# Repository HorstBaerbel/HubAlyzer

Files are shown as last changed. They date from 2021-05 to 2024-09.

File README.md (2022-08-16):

!!! WORK IN PROGRESS !!!

# HubAlyzer

<p align="center">
    
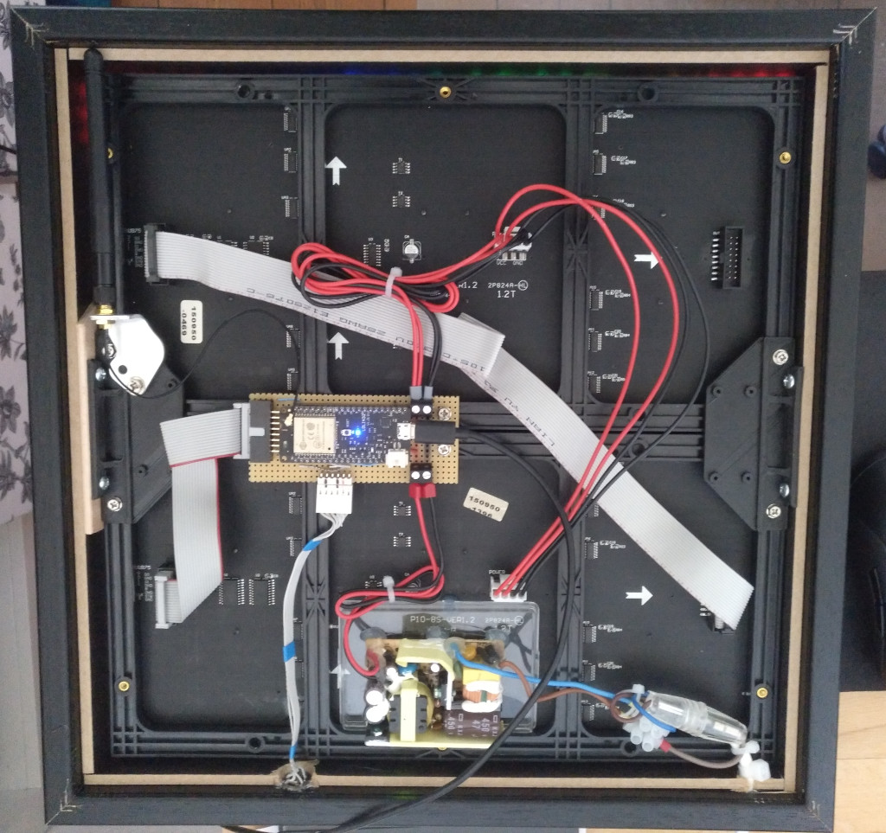
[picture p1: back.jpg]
back
        
    </span>
</p>

## Making the PCB

See the [KiCad](KiCad) directory for the PCB files. You can upload the PCB file straight to e.g. [Aisler.net](Aisler.net) and get some pretty PCBs made.

<p align="center">
    <span>
        <img src="pcb.jpg" width=80%;" title="pcb">
    </span>
</p>

## Updating your network configuration

Edit [HubAlyzer/network_config.h](HubAlyzer/network_config.h) and put your WiFi network and password there. Make sure NOT to commit the file and upload to GitHub when forking the repo!

## Problems compiling the Arduino code

Recently there were some problems with SmartMatrix and the ESP32 Arduino libraries, see [this](https://github.com/pixelmatix/SmartMatrix/issues/165).

## Problems flashing the Arduino code

If the Arduino IDE fails to connect to the board / upload the code, see [this](https://github.com/espressif/arduino-esp32/issues/2516).

## License

If you want to build your own soft- or hardware based on this, you can. See the [MIT LICENSE](LICENSE).

## TODO

* Clean up code
* Clean up esp32-i2s-slm fork
* Merge ArduinoFFT master
* More draw functions
* Draw function switching
* Add rotary encoder handling
* And Bluetooth MIDI and/or WiFi interface

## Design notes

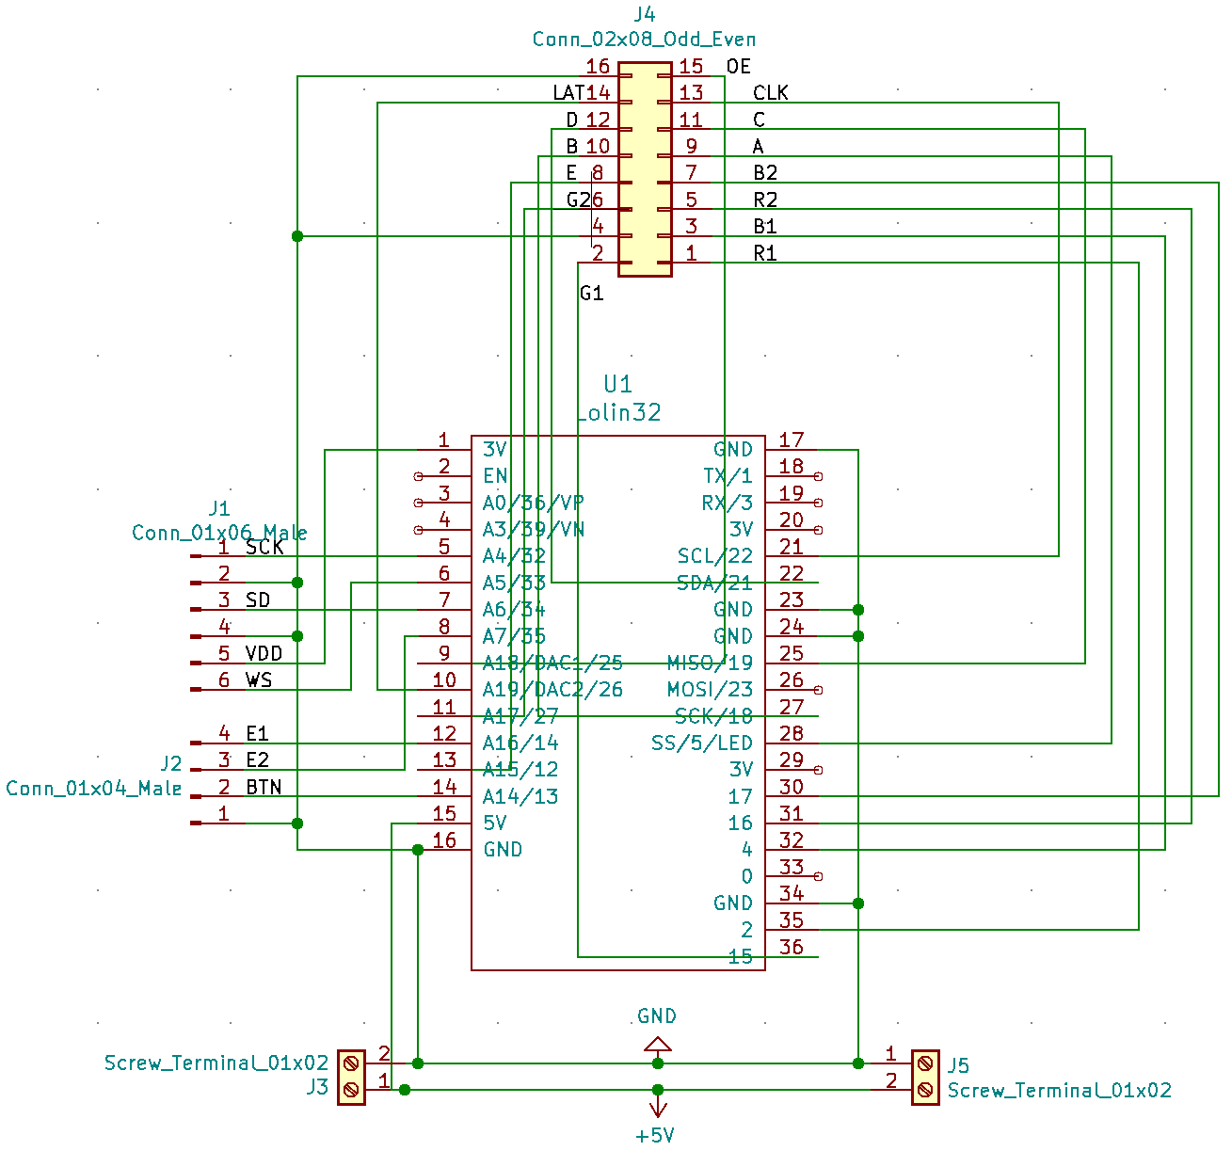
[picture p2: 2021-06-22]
schematics.png

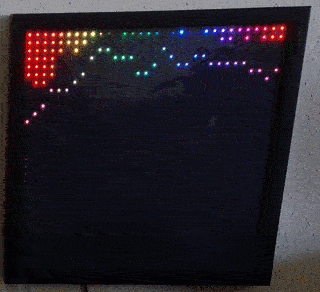
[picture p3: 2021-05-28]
animation.gif

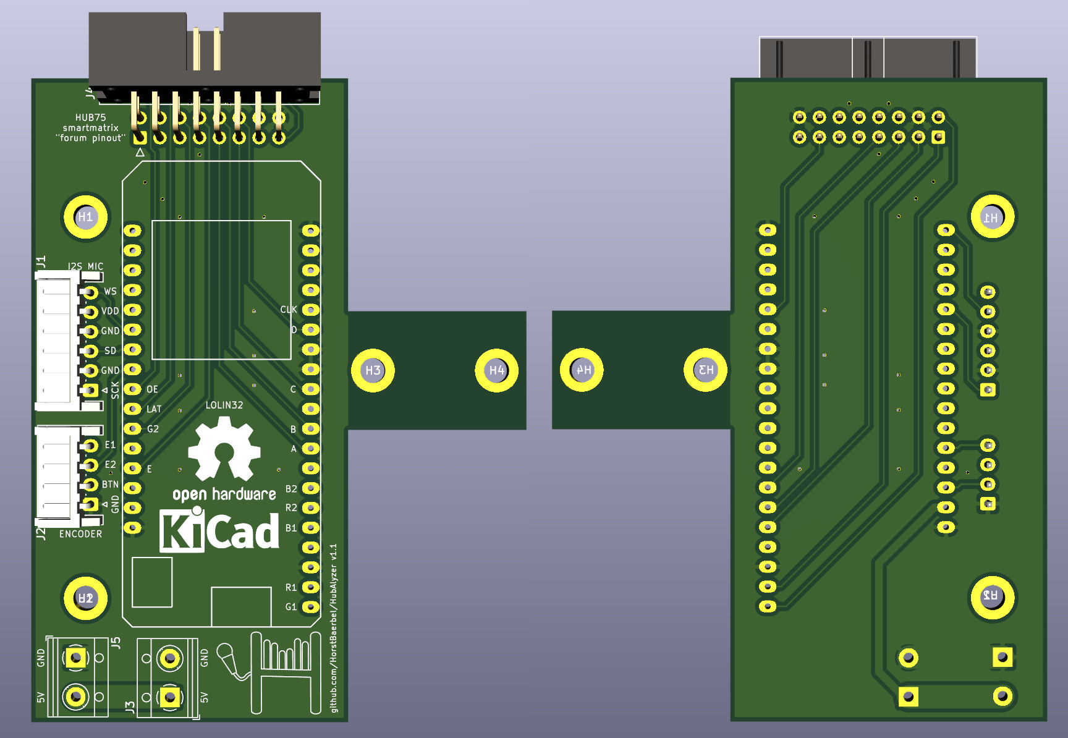
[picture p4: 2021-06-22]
pcb.jpg

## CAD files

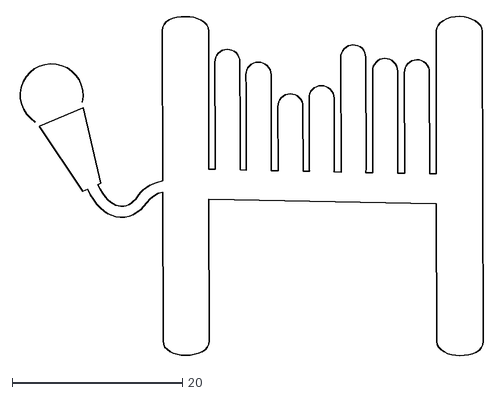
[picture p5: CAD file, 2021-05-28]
KiCad/logo.dxf
54.9 x 39.9

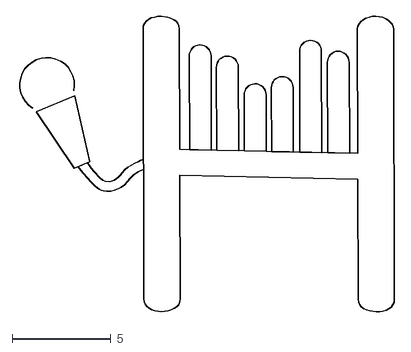
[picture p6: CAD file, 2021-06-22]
logo.dxf
19.2 x 15.0

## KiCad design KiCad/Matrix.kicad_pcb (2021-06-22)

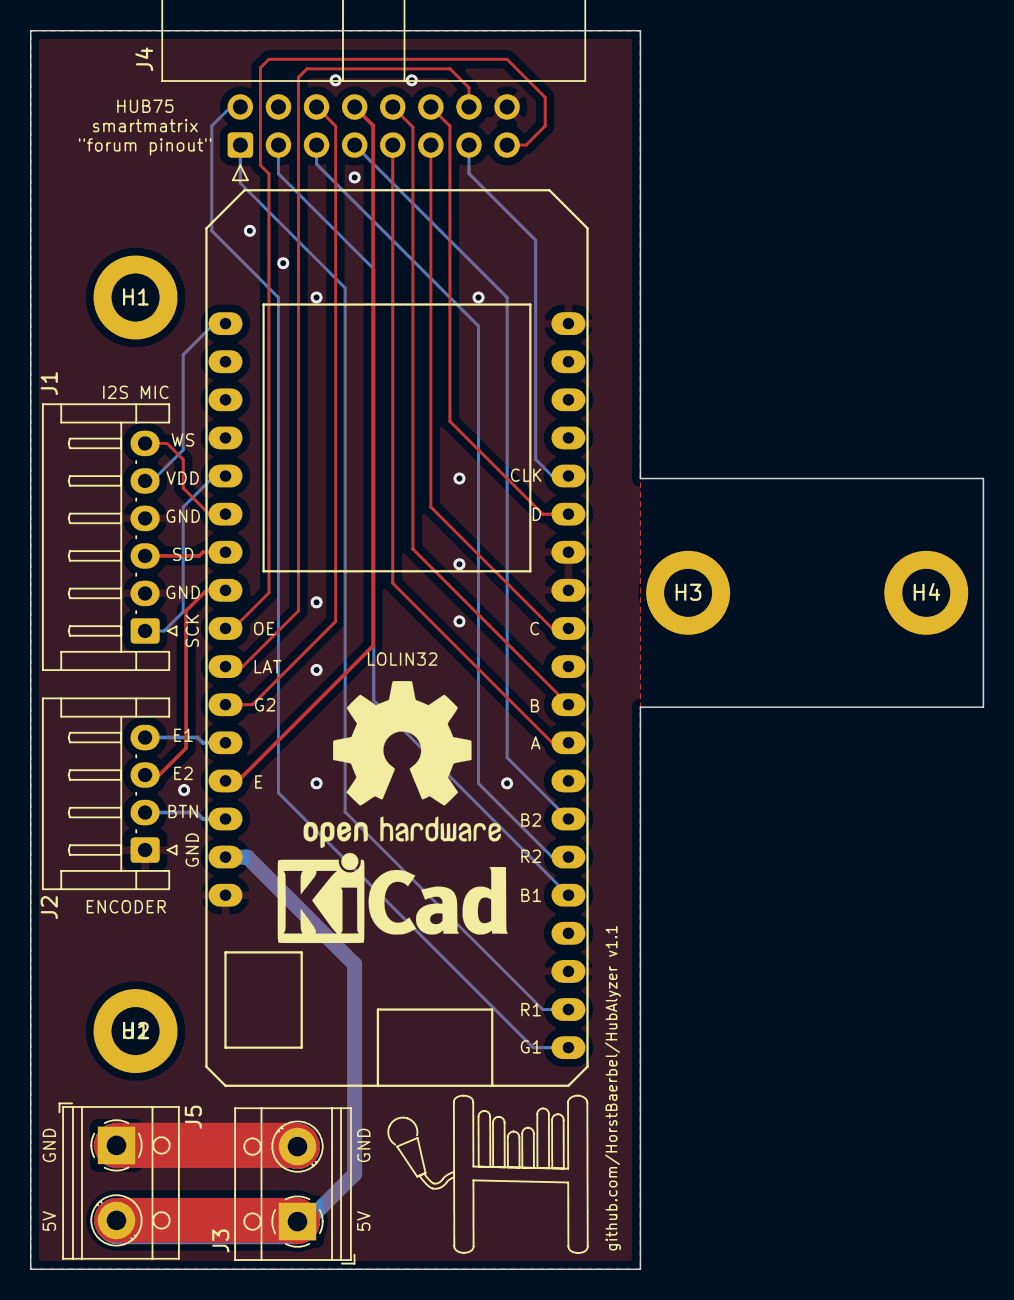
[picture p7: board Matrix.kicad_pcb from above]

Board: 2 copper layers, 63.5 x 82.5 mm, 12 parts (0 on the bottom side), 23 nets.

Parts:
H1, H2, H3, H4: MountingHole; MountingHole_3.2mm_M3_DIN965_Pad
H5: OH logo; OSHW-Logo2_14.6x12mm_SilkScreen
H6: KiCad logo; KiCad-Logo_6mm_SilkScreen
J1: Conn_01x06_Male; JST_EH_S6B-EH_1x06_P2.50mm_Horizontal
J2: Conn_01x04_Male; JST_EH_S4B-EH_1x04_P2.50mm_Horizontal
J3, J5: Screw_Terminal_01x02; TerminalBlock_RND_205-00012_1x02_P5.00mm_Horizontal
J4: Conn_02x08_Odd_Even; IDC-Header_2x08_P2.54mm_Horizontal
U1: Lolin32

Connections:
+5V: J3.1, J5.2, U1.15
/A: J4.9, U1.28
/B: J4.10, U1.27
/B1: J4.3, U1.32
/B2: J4.7, U1.30
/BTN: J2.2, U1.14
/C: J4.11, U1.25
/CLK: J4.13, U1.21
/D: J4.12, U1.22
/E: J4.8, U1.13
/E1: J2.4, U1.12
/E2: J2.3, U1.8
/G1: J4.2, U1.36
/G2: J4.6, U1.11
/LAT: J4.14, U1.10
/OE: J4.15, U1.9
/R1: J4.1, U1.35
/R2: J4.5, U1.31
/SCK: J1.1, U1.5
/SD: J1.3, U1.7
/VDD: J1.5, U1.1
/WS: J1.6, U1.6
GND: J1.2, J1.4, J2.1, J3.2, J4.4, J4.16, J5.1, U1.16, U1.17, U1.23, U1.24, U1.34

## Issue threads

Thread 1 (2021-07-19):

'ArduinoFFT' was not declared in this scope

wilson3682, 2021-07-19:
Hi, when I try to compile the sketch, this is the error I'm getting. Do you know what could be happening? All libraries needed have been installed including the arduinoFFT library.

line 122   auto fft = ArduinoFFT<float>(real, imag, SAMPLE_COUNT, SAMPLE_RATE_HZ, weighingFactors);

Thanks for your help!

HorstBaerbel, 2021-07-19:
Hi wilson3682. You need to use the [development version](https://github.com/kosme/arduinoFFT/tree/develop) of the ArduinoFFT library.

HorstBaerbel, 2021-07-19:
There's also some files still missing due to problems with the submodules. I will update the code in the next few days when I find time and respond here.

wilson3682, 2021-07-19:
Thanks HorsBaerbel for your help! I deleted the arduinoFFT library installed through arduino and placed the dev library manually and now it compiles. Thanks again!

HorstBaerbel, 2021-07-19:
I'd be surprised if it worked because you're probably missing some submodule code. I've updated the repos with the submodules and my current version of the code, but this is WIP. Will update the code in the next weeks. I've killed my ESP32 and am currently waiting for an replacement...

Closed 2021-07-19.

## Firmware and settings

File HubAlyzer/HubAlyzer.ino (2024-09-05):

/*
   Based on SpectrumAnalyzerBasic by Paul Stoffregen included in the Teensy Audio Library
   Modified by Jason Coon for the SmartMatrix Library
   If you are having trouble compiling, see
   the troubleshooting instructions here:
   https://github.com/pixelmatix/SmartMatrix/#external-libraries

   Also based on the ESP32 I2S SLM project by Ivan Kostoski:
   https://github.com/ikostoski/esp32-i2s-slm

   Requires the following libraries:
   Arduino Fast Fourier Transform library: https://github.com/kosme/arduinoFFT
   SmartMatrix v4 or higher: https://github.com/pixelmatix/SmartMatrix/releases
*/

#include "esp32-i2s-slm/filters.h"
#include "esp32-i2s-slm/i2s_mic.h"
#include "approx.h"  // fast log10f and sincosf approximation
#include <cmath>

static constexpr unsigned SAMPLE_RATE_HZ = 48000;  // Hz, fixed to design of IIR filters. Determines maximum frequency that can be analysed by the FFT Fmax=sampleF/2.
static constexpr unsigned SAMPLE_COUNT = 1024;      // ~10ms sample time, must be power-of-two
float samples[SAMPLE_COUNT];                       // Raw microphone sample storage

// NOTE: Some microphones require at least a DC-Blocker filter
#define MIC_EQUALIZER INMP441                    // See below for defined IIR filters or set to 'None' to disable
static constexpr float MIC_OFFSET_DB = 3.0103f;  // Default offset (sine-wave RMS vs. dBFS). Modify this value for linear calibration
// Customize these values from microphone datasheet
static constexpr int MIC_SENSITIVITY = -26.0f;  // dBFS value expected at MIC_REF_DB (Sensitivity value from datasheet)
static constexpr int MIC_REF_DB = 94.0f;        // Value at which point sensitivity is specified in datasheet (dB)
static constexpr int MIC_OVERLOAD_DB = 120.0f;  // dB - Acoustic overload point / Maximum Acoustic Input
static constexpr int MIC_NOISE_DB = 33.0f;      // dB - Noise floor
static constexpr unsigned MIC_BITS = 24;        // valid number of bits in I2S data

constexpr float MIC_REF_AMPL = powf(10.0f, float(MIC_SENSITIVITY) / 20.0f) * ((1 << (MIC_BITS - 1)) - 1);  // Microphone reference amplitude value

// Convert microphone amplitude to dB values
float MicAmplitudeToDb(float v) {
  return MIC_OFFSET_DB + MIC_REF_DB + 20.0f * log10f_fast(v / MIC_REF_AMPL);
}

auto mic = Microphone_I2S<SAMPLE_COUNT, 33, 32, 34, I2S_NUM_0, MIC_BITS, false, SAMPLE_RATE_HZ>(MIC_EQUALIZER);

// ------------------------------------------------------------------------------------------

#include "fft.h"
#include "normalization.h"
#include "spectrum.h"
#include "beat_detection.h"

static constexpr unsigned NR_OF_BANDS = 32;
static constexpr unsigned MAX_ANALYSIS_FREQUENCY_HZ = 4000;

auto fft = FFT<SAMPLE_COUNT, SAMPLE_RATE_HZ>(&samples);
auto normalization = Normalization<SAMPLE_COUNT, MIC_NOISE_DB, MIC_OVERLOAD_DB, MAX_ANALYSIS_FREQUENCY_HZ, SAMPLE_RATE_HZ>(MicAmplitudeToDb);
auto spectrum = Spectrum<SAMPLE_COUNT, NR_OF_BANDS, MAX_ANALYSIS_FREQUENCY_HZ, SAMPLE_RATE_HZ>();
auto beats = BeatDetection<SAMPLE_COUNT, MAX_ANALYSIS_FREQUENCY_HZ, SAMPLE_RATE_HZ, 50>();

// ------------------------------------------------------------------------------------------

#include <WiFi.h>

//#define ENABLE_OTA
#ifdef ENABLE_OTA
#include <ESPmDNS.h>
#include <WiFiUdp.h>
#include <ArduinoOTA.h>
#endif

//#define ENABLE_BLUETOOTH
#ifdef ENABLE_BLUETOOTH
#include "BluetoothSerial.h"
//#include "esp_gap_bt_api.h"
#if !defined(CONFIG_BT_ENABLED) || !defined(CONFIG_BLUEDROID_ENABLED)
#error Bluetooth is not enabled! Please run `make menuconfig` to and enable it
#endif
BluetoothSerial SerialBT;
#endif

// Configure your WiFi and Bluetooth settings here:
#include "network_config.h"

// ------------------------------------------------------------------------------------------

#ifndef GPIO_PIN_MUX_REG
#include "esp32-hal.h"
#include "hal/gpio_types.h"
#include "soc/gpio_periph.h"
#endif

#define GPIOPINOUT ESP32_FORUM_PINOUT
#include <MatrixHardware_ESP32_V0.h>
#include <SmartMatrix.h>

#define COLOR_DEPTH 24                                                    // known working: 24, 48 - If the sketch uses type `rgb24` directly, COLOR_DEPTH must be 24
static constexpr unsigned kMatrixWidth = 32;                              // known working: 32, 64, 96, 128
static constexpr unsigned kMatrixHeight = 32;                             // known working: 16, 32, 48, 64
static constexpr unsigned kRefreshDepth = 24;                             // known working: 24, 36, 48
static constexpr unsigned kDmaBufferRows = 4;                             // known working: 2-4, use 2 to save memory, more to keep from dropping frames and automatically lowering refresh rate
static constexpr unsigned kPanelType = SMARTMATRIX_HUB75_16ROW_MOD8SCAN;  // use SMARTMATRIX_HUB75_16ROW_MOD8SCAN for common 16x32 panels
static constexpr unsigned kMatrixOptions = (SM_HUB75_OPTIONS_NONE);       // see http://docs.pixelmatix.com/SmartMatrix for options
static constexpr unsigned kBackgroundLayerOptions = (SM_BACKGROUND_OPTIONS_NONE);
SMARTMATRIX_ALLOCATE_BUFFERS(matrix, kMatrixWidth, kMatrixHeight, kRefreshDepth, kDmaBufferRows, kPanelType, kMatrixOptions);
SMARTMATRIX_ALLOCATE_BACKGROUND_LAYER(backgroundLayer, kMatrixWidth, kMatrixHeight, COLOR_DEPTH, kBackgroundLayerOptions);

// ------------------------------------------------------------------------------------------

#include "effectpipeline.h"
#include "effects_draw.h"
#include "effects_spectrum.h"
#include "effects_feedback.h"
#include "screen.h"

auto screen = SMLayerScreen<kMatrixWidth, kMatrixHeight, kBackgroundLayerOptions>(backgroundLayer);
auto effects = std::vector<Effect::SPtr>({ std::make_shared<Effects::FillColor<kMatrixWidth, kMatrixHeight, Effect::Type::ToDestination>>(), std::make_shared<Effects::DrawSpectrum<kMatrixWidth, kMatrixHeight, NR_OF_BANDS>>() });
//auto effects = std::vector<Effect::SPtr>({ std::make_shared<Effects::MoveFromCenter<kMatrixWidth, kMatrixHeight>>(), std::make_shared<Effects::ChangeBrightness<kMatrixWidth, kMatrixHeight>>(), std::make_shared<Effects::DrawSpectrum<kMatrixWidth, kMatrixHeight, NR_OF_BANDS>>() });
auto pipeline = EffectPipeline<kMatrixWidth, kMatrixHeight>(effects);

// TODO: Functions to randomize effect pipeline and configure effects

// ------------------------------------------------------------------------------------------

#ifdef ENABLE_BLUETOOTH
void bluetoothCallback(esp_spp_cb_event_t event, esp_spp_cb_param_t *param) {
  Serial.print("Bluetooth event: ");
  Serial.println(event);
  if (event == ESP_SPP_SRV_OPEN_EVT) {
    Serial.println("Client Connected");
  }
  if (event == ESP_SPP_CLOSE_EVT) {
    Serial.println("Client disconnected");
  }
}
#endif

#ifdef ENABLE_OTA
void checkOTA() {
  static auto lastCheckTime = millis();
  auto now = millis();
  if (now - lastCheckTime >= 2000) {
    lastCheckTime = now;
    ArduinoOTA.handle();
  }
}
#endif

void setup() {
  Serial.begin(115200);
  Serial.println("Running setup");
  // Generate host name for WiFi and Bluetooth
  String chipId = String((uint32_t)ESP.getEfuseMac(), HEX);
  chipId.toUpperCase();
  String hostName = String("Matrix-") + chipId;

#ifdef ENABLE_OTA
  // Set up WiFi
  Serial.println("Setting up WiFi");
  WiFi.hostname(hostName);
  WiFi.mode(WIFI_STA);
  WiFi.begin(wifiSsid, wifiPassword);
  while (WiFi.waitForConnectResult() != WL_CONNECTED) {
    Serial.println("WiFi connection Failed! Rebooting...");
    delay(5000);
    ESP.restart();
  }
  // Set up OTA updates
  Serial.println("Setting up OTA updates");
  ArduinoOTA.onStart([]() {
              String type;
              if (ArduinoOTA.getCommand() == U_FLASH)
                type = "sketch";
              else  // U_SPIFFS
                type = "filesystem";
              // NOTE: if updating SPIFFS this would be the place to unmount SPIFFS using SPIFFS.end()
              Serial.println("Start updating " + type);
            })
    .onEnd([]() {
      Serial.println("\nEnd");
    })
    .onProgress([](unsigned int progress, unsigned int total) {
      Serial.printf("Progress: %u%%\r", (progress / (total / 100)));
    })
    .onError([](ota_error_t error) {
      Serial.printf("Error[%u]: ", error);
      if (error == OTA_AUTH_ERROR)
        Serial.println("Auth Failed");
      else if (error == OTA_BEGIN_ERROR)
        Serial.println("Begin Failed");
      else if (error == OTA_CONNECT_ERROR)
        Serial.println("Connect Failed");
      else if (error == OTA_RECEIVE_ERROR)
        Serial.println("Receive Failed");
      else if (error == OTA_END_ERROR)
        Serial.println("End Failed");
    });
  ArduinoOTA.begin();
  Serial.print("Hostname: ");
  Serial.println(hostName);
  Serial.print("IP address: ");
  Serial.println(WiFi.localIP());
#else
  // Turn Wifi off
  Serial.println("Turning WiFi off");
  WiFi.mode(WIFI_OFF);
#endif

#ifdef ENABLE_BLUETOOTH
  // SerialBT.register_callback(bluetoothCallback);
  if (!SerialBT.begin(hostName)) {
    Serial.println("An error occurred initializing Bluetooth!");
  } else {
    Serial.print("Bluetooth initialized. Device name is ");
    Serial.println(hostName);
  }
  // Set up Bluetooth classic for legacy pairing
  if (esp_bt_gap_set_pin(ESP_BT_PIN_TYPE_FIXED, strlen(bluetoothPinCode), reinterpret_cast<uint8_t *>(bluetoothPinCode)) == ESP_OK) {
    Serial.print("Bluetooth pin code set to ");
    Serial.println(bluetoothPinCode);
  } else {
    Serial.println("Setting bluetooth pin code failed!");
  }
#endif

  // initialize LED matrix
  matrix.addLayer(&backgroundLayer);
  matrix.setBrightness(128);
  matrix.setRefreshRate(50);
  matrix.begin();
  // initialize microphone
  mic.begin();
  Serial.println("Starting sampling from mic");
  mic.startSampling();
}

//#define PRINT_LOOP_TIME
#ifdef PRINT_LOOP_TIME
long lastLoopTime = 0;
#endif

void loop() {
  Serial.println("Starting loop");
  // Get samples from other ESP32 core that receives the I2S audio data
  while (xQueueReceive(mic.sampleQueue(), &samples, portMAX_DELAY)) {
    /*for (int i = 0; i < SAMPLE_COUNT/4; ++i)
    {
      Serial.print(String(samples[i], 2) + String(", "));
    }*/
    // apply A-Weighting filter for perceptive loudness. See: https://www.noisemeters.com/help/faq/frequency-weighting/
    A_weighting.applyFilters(samples, samples, SAMPLE_COUNT);
    A_weighting.applyGain(samples, samples, SAMPLE_COUNT);
    // apply FFT to samples and return amplitudes
    auto amplitudes = fft.calculate();
    auto magnitudes = normalization.apply(amplitudes);
    auto [levels, peaks] = spectrum.update(magnitudes);
    auto probabilities = beats.update(levels);
    bool isBeat = beats.timeSinceLastBeatMs() < 50;
    //  Serial.println(beats.timeSinceLastBeatMs());
    pipeline.render(levels, peaks, isBeat);
    screen.blit(pipeline.output());
    screen.swap();
    // Enable over-the-air updates
#ifdef ENABLE_OTA
    checkOTA();
#endif
#ifdef PRINT_LOOP_TIME
    auto currentLoopTime = millis();
    Serial.print(currentLoopTime - lastLoopTime);
    Serial.println(" ms");
    lastLoopTime = currentLoopTime;
#endif
  }
}

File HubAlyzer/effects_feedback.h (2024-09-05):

#pragma once

#include "color.h"
#include "vec.h"
#include "effect.h"

#include <cmath>

namespace Effects
{

    // Move screen from center an amount to the left or right
    template <unsigned WIDTH, unsigned HEIGHT>
    class MoveFromCenter : public Effect
    {
    public:
        virtual auto type() const -> Type override
        {
          return Effect::Type::SourceToDestination;
        }

        virtual auto render(RGBf *dest, const RGBf *src, [[maybe_unused]] const float *levels, [[maybe_unused]] const float *peaks, [[maybe_unused]] bool isBeat) -> void override
        {
            moveFromCenterVertical<WIDTH, HEIGHT>(dest, src, m_dist);
        }

    private:
        template <unsigned SRC_WIDTH, unsigned SRC_HEIGHT>
        auto moveFromCenterHorizontal(RGBf *dest, const RGBf *src, float dist) -> void
        {
            for (int32_t y = 0; y < HEIGHT; y++)
            {
                const auto ty = y * SRC_WIDTH;
                float u = 0;
                for (int32_t x = 0; x < WIDTH / 2; x++)
                {
                  float tx = std::fmod(u, SRC_WIDTH - 1);
                  *dest++ = src[static_cast<int>(ty + tx)];
                  u += m_dist;
                }
                u = WIDTH / 2;
                for (int32_t x = WIDTH / 2; x < WIDTH; x++)
                {
                  float tx = std::fmod(u, SRC_WIDTH - 1);
                  *dest++ = src[static_cast<int>(ty + tx)];
                  u += m_dist;
                }
            }
        }

        template <unsigned SRC_WIDTH, unsigned SRC_HEIGHT>
        auto moveFromCenterVertical(RGBf *dest, const RGBf *src, float dist) -> void
        {
            for (int32_t x = 0; x < WIDTH; x++)
            {
                auto dst = dest + x;
                float v = HEIGHT / 2 - 1;
                for (int32_t y = HEIGHT / 2 - 1; y > 0; y--)
                {
                  float ty = std::fmod(v, SRC_HEIGHT - 1);
                  *dst = src[static_cast<int>(ty * SRC_WIDTH)];
                  dst += SRC_WIDTH;
                  v -= m_dist;
                }
                v = HEIGHT / 2;
                for (int32_t y = HEIGHT / 2; y < HEIGHT; y++)
                {
                  float ty = std::fmod(v, SRC_HEIGHT - 1);
                  *dst = src[static_cast<int>(ty * SRC_WIDTH)];
                  dst += SRC_WIDTH;
                  v += m_dist;
                }
            }
        }

        float m_dist = 0.5F;
    };

    // Rotate + zoom + blit buffer
    template <unsigned WIDTH, unsigned HEIGHT>
    class RotoBlit : public Effect
    {
    public:
        virtual auto type() const -> Type override
        {
          return Effect::Type::SourceToDestination;
        }

        virtual auto render(RGBf *dest, const RGBf *src, [[maybe_unused]] const float *levels, [[maybe_unused]] const float *peaks, [[maybe_unused]] bool isBeat) -> void override
        {
            rotoBlit<WIDTH, HEIGHT, true>(dest, src, m_position, m_angle, m_scale);
        }

    private:
        // Rotate + zoom + blit screen
        // @param shift Shift in x and y. Must be in (0,1)
        // @param angle Rotation angle in radians. Must be in (0,2*PI)
        // @param zoom Zoom factor. Must be > 0
        template <unsigned SRC_WIDTH, unsigned SRC_HEIGHT, bool ADDITIVE = false>
        auto rotoBlit(RGBf *dest, const RGBf *src, const vec2f_t &position, float angle, float scale) -> void
        {
            float sa = std::sin(angle);
            float ca = std::cos(angle);
            float invScaleY = 1.0F / (static_cast<float>(HEIGHT) / static_cast<float>(WIDTH) * scale);
            float pa = ca / invScaleY;
            float pb = -sa / invScaleY;
            float pc = sa / invScaleY;
            float pd = ca / invScaleY;
            float pa0 = pa * (position.x - WIDTH / 2);
            float pb0 = pb * (position.y - HEIGHT / 2);
            float pc0 = pc * (position.x - WIDTH / 2);
            float pd0 = pd * (position.y - HEIGHT / 2);
            const float uY = pb - pa * WIDTH;
            const float vY = pd - pc * WIDTH;
            float u = pb0 + pa0;
            float v = pd0 + pc0;
            for (int32_t y = 0; y < HEIGHT; y++)
            {
                for (int32_t x = 0; x < WIDTH; x++)
                {
                    float tx = std::fmod(u, SRC_WIDTH - 1);
                    float ty = std::fmod(v, SRC_HEIGHT - 1);
                    if constexpr (ADDITIVE)
                    {
                        auto out = *dest;
                        const auto & in = src[static_cast<int>(ty * SRC_WIDTH + tx)];
                        out.r = clamp(in.r + out.r, 0.0F, 1.0f);
                        out.g = clamp(in.g + out.g, 0.0F, 1.0f);
                        out.b = clamp(in.b + out.b, 0.0F, 1.0f);
                        *dest++ = out;
                    }
                    else
                    {
                        *dest++ = src[static_cast<int>(ty * SRC_WIDTH + tx)];
                    }
                    u += pa;
                    v += pc;
                }
                u += uY;
                v += vY;
            }
        }

        vec2f_t m_position = {WIDTH / 2, HEIGHT / 2};
        float m_angle = 0;
        float m_scale = 1.0F;
    };

    // Fade screen to black or white. t must be in [-1,1]
    template <unsigned WIDTH, unsigned HEIGHT>
    class ChangeBrightness : public Effect
    {
    public:
        virtual auto render(RGBf *dest, const RGBf *src, [[maybe_unused]] const float *levels, [[maybe_unused]] const float *peaks, [[maybe_unused]] bool isBeat) -> void override
        {
            changeBrightness(dest, src, m_t);
        }

    private:
        auto changeBrightness(RGBf *dest, [[maybe_unused]] const RGBf *src, float t) -> void
        {
            for (unsigned i = 0; i < WIDTH * HEIGHT; i++)
            {
                // note that these input colors are not linear RGB. we should probably gamma-correct them
                auto color = dest[i];
                auto r = color.r + t * color.r;
                auto g = color.g + t * color.g;
                auto b = color.b + t * color.b;
                color.r = clamp(r, 0.0F, 1.0F);
                color.g = clamp(g, 0.0F, 1.0F);
                color.b = clamp(b, 0.0F, 1.0F);
                dest[i] = color;
            }
        }

        float m_t = 1.0F;
    };

    // Decrease/increase screen saturation. t must be in [-1,1]
    template <unsigned WIDTH, unsigned HEIGHT>
    class ChangeSaturation : public Effect
    {
    public:
        virtual auto render(RGBf *dest, const RGBf *src, [[maybe_unused]] const float *levels, [[maybe_unused]] const float *peaks, [[maybe_unused]] bool isBeat) -> void override
        {
            changeSaturation(dest, src, m_t);
        }
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

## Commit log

2021-05-28 Add Arduino sketch
2021-05-28 Add PCB and schematics images
2021-06-22 Update board to use E line
    [Matrix.kicad_pcb, Matrix.sch, logo.dxf]
2021-07-19 Add submodules to arduino dir
2021-07-19 Fix code and update README
    [HubAlyzer.ino]
2022-07-19 Reduce number of samples to improve responsiveness
2022-08-16 Fix normalization and spectrum calculation
    [normalization.h, spectrum.h]
2024-09-02 Fix frame buffer overflow
    [effects_spectrum.h]
